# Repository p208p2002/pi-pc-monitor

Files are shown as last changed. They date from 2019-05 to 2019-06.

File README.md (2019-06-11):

# LED電腦資源監控燈 / Pi PC monitor
A Pi PC state monitor design for NUTC final project.

Monitor with CPU and RAM usage state.

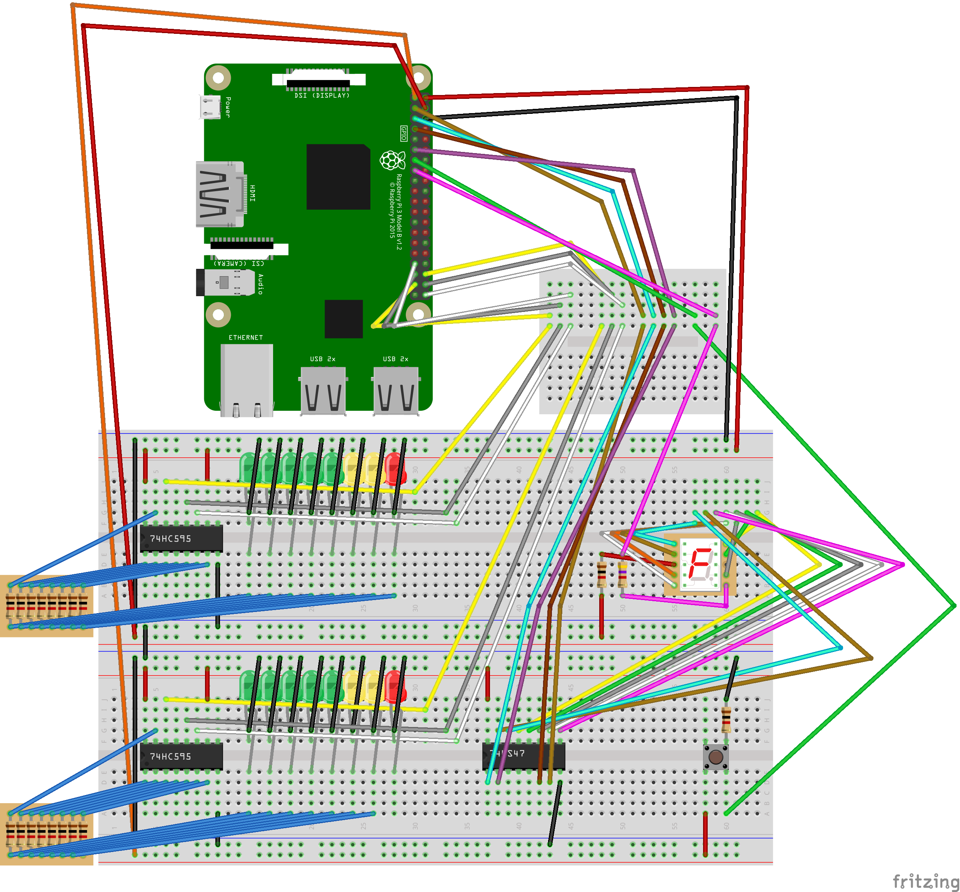
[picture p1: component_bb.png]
component


[Video 1](https://www.youtube.com/watch?v=h-WTSqjy7dE)

[Video 2](https://www.youtube.com/watch?v=xZc-PM7hHug)

# Usage
- put `server_pi.py` on Rasbperry Pi and run with Python 3
- put `client_pc.py` on your PC and run with `python3 --host=YOUR_PI_SERVER_IP`

# File description
file name     | description
--------------|------------
client_pc.py  | client code
core.py       | get PC state info (for client)
server_pi.py  | server code
ic.py         | ic driver class (for server)
component.fzz | Fritzing file
document.docx | design document

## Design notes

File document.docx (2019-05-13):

## Pi期末專題

Physical PC state monitor with Pi

黃柏鈞

黃耕易

吳靚玹

鄭安志

侯宇濤

1. 專題大綱

使用Raspberry Pi搭建一組PC資源狀態監控器，可實時反映被監控端CPU與RAM使用率，監控主機與被控端將以socket進行通訊並搭配Pi的GPIO將狀態以實體元件顯示。

2. 系統目的

有時候我們常常使用電腦進行大量資源的運算，但是卻常常不知道電腦目前的負載狀態，到底是處於高負載還是有閒置效能。

相比直接將資源狀態顯是於螢幕上的軟體，本專題使用的實體燈號具有以下優勢:

1. 在電腦全螢幕模式下無須切換視窗(相較非懸浮監控軟體)

2. 不會因佔用畫面而導致遮蓋掉畫面資訊(相較懸浮監控軟體)

3. 獨立顯示設備可作為桌面裝飾品

4. 更容易了解電腦負載狀態

3. 系統架構

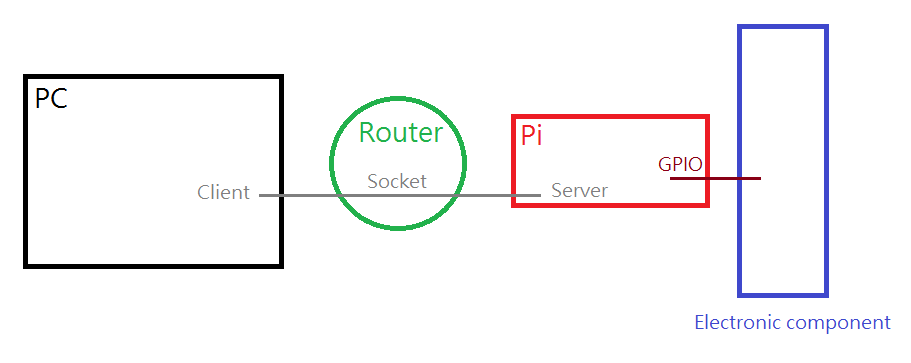
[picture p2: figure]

- PC與Pi會在同一個區域網路
- 在Pi上建立socket server負責接收資料
- PC上則有socket client負責丟資料
- Pi接受到資料後進行解析並且將結果透過GPIO輸出至電子元件

4. 系統流程圖

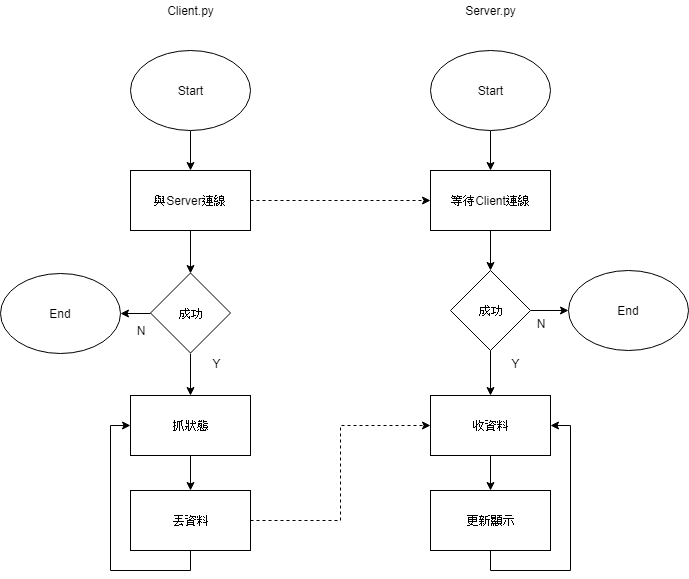
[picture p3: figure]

5. 使用技術與設備

名稱 | 說明
Raspberry Pi 3 Model B+ | 監控主機與電子元件控制
Python 3 | 主要開發語言
Git | 版本控制

6. 使用元件

名稱 | 數量 | 用途
LED(綠) | 10 | 狀態陣列
LED(黃) | 4 | 狀態陣列
LED(紅) | 2 | 狀態陣列
74595 | 2 | LED控制
7447 | 1 | 七段顯示器控制
七段顯示器 | 1 | 顯示Server IP資訊
按鈕 | 1 | 功能觸發
1k 電阻 | 18 | 七段顯示器與LED電阻
4.7k 電阻 | 1 | 七段顯示器電阻

7. 電路佈局

7.1 總覽

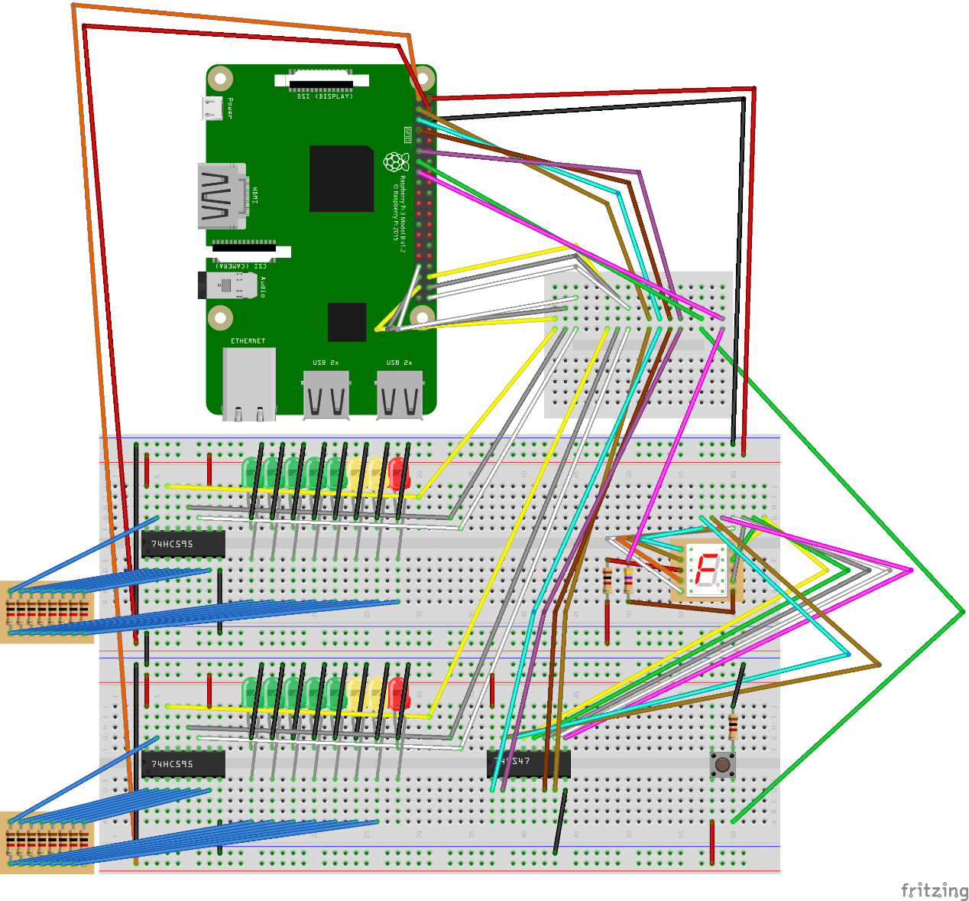
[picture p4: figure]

7.2 局部特寫與功能說明

7.2.1 Part A

gpio | 功能
2 | 7447 PIN A
3 | 7447 PIN B
4 | 7447 PIN C
17 | 7447 PIN D
22 | 小數點
27 | 按鈕

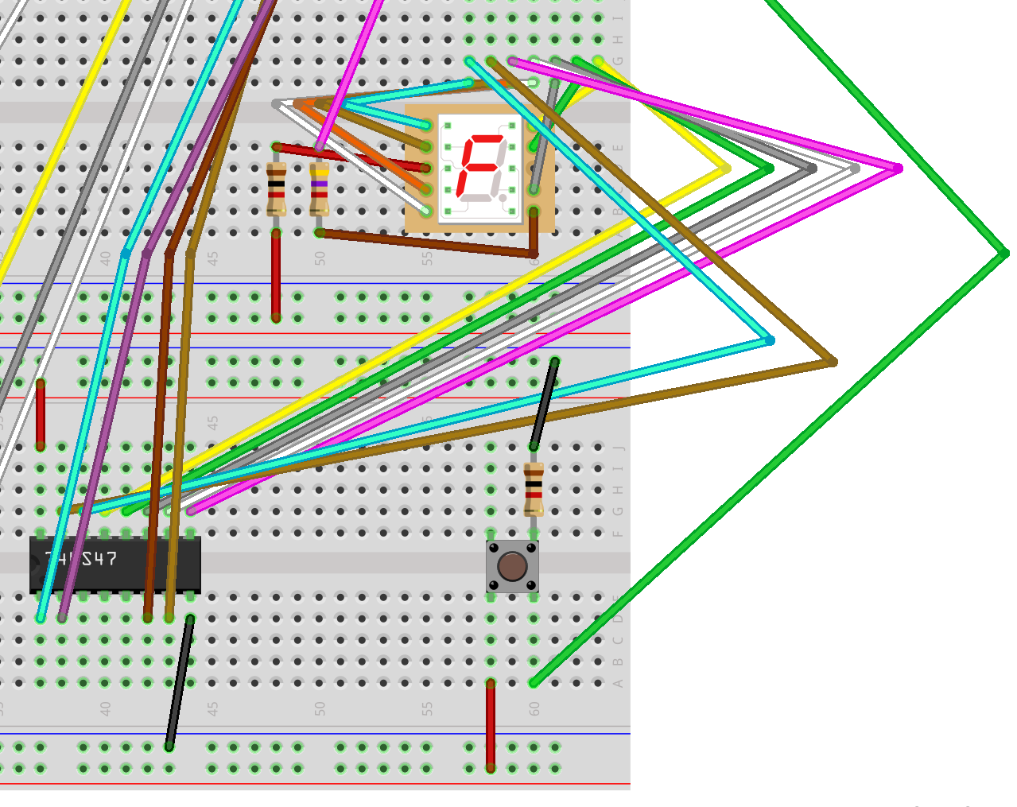
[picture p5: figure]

gpio 22

gpio 27

gpio 17

gpio 4

gpio 3

gpio 2

7.2.2 Part B

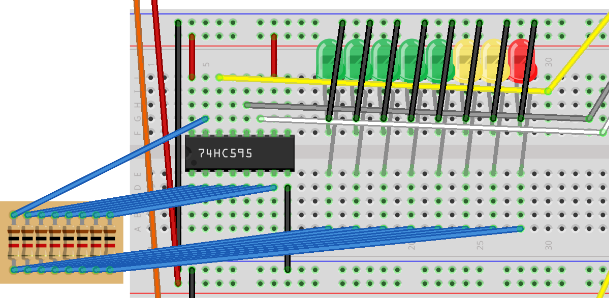
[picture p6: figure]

gpio 21/13

gpio 20/19

gpio 16/26

gpio | 功能
16/26 | 74595 DS
20/19 | 74595 STCP
21/13 | 74595 SHCP

8. 通訊格式定義

資料格式:Json

格式結構:

{

"Type":EVENT_TYPE

"Data":DATA,

}

8.1 EVENT TYPE

8.1.1 BASIC_MSG

包含被監控端基本資訊

{

"Type": "BASIC_MSG",

"Data": {

"CPU_Model": String,

"CPU_Count": Int,

"CPU_Count_Logical": Int,

"RAM_Total_Size": Float

}

}

8.1.2. USAGE_MSG

包含被監控端資源使用量資訊

{

"Type": "USAGE_MSG",

"Data": {

"CPU_PERCENT":String,

"MEM_USED": Int

}

}

9. 系統部屬與操作

1. 參照5、6章節先將硬體準備完畢

2. 至Project Repo(參閱第9章節)將檔案下載

3. 將client_pc.py與core.py放置在欲監控之電腦

4. 將server_pi.py與ic.py放置在Raspberry Pi

5. 確保Raspberry Pi與欲監控之電腦在同一區域網路

5. 在Raspberry Pi輸入指令python3 server_pi.py運行Server端

6. 按下Raspberry Pi之”按鈕”，七段顯示器將顯示Server IP

7. 在欲監控之電腦輸入指令python3 client_py –port=YOUR_SERVER_IP

YOUR_SERVER_IP為七段顯示器所顯示IP

10. 附件

1. Project Repo : https://github.com/p208p2002/pi-pc-monitor

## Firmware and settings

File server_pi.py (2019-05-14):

import socket
import sys
import argparse
import json
import time
import RPi.GPIO as gpio
import signal
import sys
from ic import IC74595,IC7447

host = ''
data_payload = 4096
backlog = 1

#
gpio.setmode(gpio.BCM)

#
DS = 16     # Serial Data
STCP = 20  # Latch
SHCP = 21  # Clock

DS2 = 26
STCP2 = 19
SHCP2 = 13

IC_7447_A = 2
IC_7447_B = 3
IC_7447_C = 4
IC_7447_D = 17

#
MachineInfo={}
LED_STATE = [0,128,192,224,240,248,252,254,255] #0 1 2 3 4 5 6 7 8

#
BTN_PIN = 27
DOT_PIN = 22
SERVER_IP = 0

#parts
digNumDisplay = IC7447(IC_7447_A,IC_7447_B,IC_7447_C,IC_7447_D,DOT_PIN)
cpuLED = IC74595(DS,STCP,SHCP)
ramLED = IC74595(DS2,STCP2,SHCP2)

def signal_handler(sig, frame):
    gpio.cleanup()
    sys.exit(0)

def showIP(channel):
    if (SERVER_IP == 0):
        digNumDisplay.off()
    else:
        for i in range(len(SERVER_IP)):
            if(SERVER_IP[i] != '.'):
                digNumDisplay.show(int(SERVER_IP[i]))
                digNumDisplay.dot(False)
            else:
                digNumDisplay.off()
                digNumDisplay.dot(True)
            time.sleep(0.5)
        digNumDisplay.off()
        digNumDisplay.dot(False)

def showServerIP():
    return [(s.connect(('8.8.8.8', 53)), s.getsockname()[0], s.close()) for s in [socket.socket(socket.AF_INET, socket.SOCK_DGRAM)]][0][1]

def showMonitorState():
    cpuModel = MachineInfo.get('CPU_Model','unkonw')
    cpuCount = MachineInfo.get('CPU_Count','unkonw')
    cpuCountLogical = MachineInfo.get('CPU_Count_Logical','unkonw')
    ramTotalSize = MachineInfo.get('RAM_Total_Size','unkonw')
    print("Machine Info:",cpuModel,str(cpuCount)+'C'+str(cpuCountLogical)+'T',str(ramTotalSize)+'MB')

def mapStateToLed(usedPrecent,pipNumber):
        led = 0
        if pipNumber == 1:
            led = cpuLED
        elif pipNumber == 2:
            led = ramLED

        if(usedPrecent==0):
            led.shiftout(LED_STATE[0])
        elif(usedPrecent<=12.5):
            led.shiftout(LED_STATE[1])
        elif(usedPrecent<=25.0):
            led.shiftout(LED_STATE[2])
        elif(usedPrecent<=37.5):
            led.shiftout(LED_STATE[3])
        elif(usedPrecent<=50.0):
            led.shiftout(LED_STATE[4])
        elif(usedPrecent<=62.5):
            led.shiftout(LED_STATE[5])
        elif(usedPrecent<=75.0):
            led.shiftout(LED_STATE[6])
        elif(usedPrecent<=87.5):
            led.shiftout(LED_STATE[7])
        elif(usedPrecent<=100):
            led.shiftout(LED_STATE[8])
        else:
            led.shiftout(0)


def updateMonitorState(jsonStr):
    global MachineInfo
    jsonData={}
    try:
        jsonData = json.loads(jsonStr)
    except:
        print("Parse json data fail")

    eventType = jsonData.get("Type")
    print("Event Type:",eventType)

    #case event type
    if(eventType == 'BASIC_MSG'):
        data = jsonData.get('Data',{})
        MachineInfo = data
    elif(eventType == 'USAGE_MSG'):
        data = jsonData.get('Data',{})
        cpuUsed = float(data.get('CPU_PERCENT',0.0))
        memUsed = float(data.get('MEM_USED',0.0))
        mapStateToLed(cpuUsed,1)
        mapStateToLed(memUsed,2)
        print(cpuUsed,memUsed)
    else:
        print('unknow event type')

    # final
    showMonitorState()


def runSocketServer(port):
    sock = socket.socket(socket.AF_INET, socket.SOCK_STREAM)
    sock.setsockopt(socket.SOL_SOCKET, socket.SO_REUSEADDR, 1)
    server_address = (host, port)
    print ("Starting up server  on %s port %s" % server_address)
    sock.bind(server_address)
    sock.listen(backlog)

    #
    print ("Waiting new client")
    client, address = sock.accept()
    print("Address:",address)

    #time out count
    timeOut = 10.0
    lastRecvTime = time.time()
    nowtime = time.time()
    while True:
        #over 10s no recv new data
        if(nowtime - lastRecvTime >= timeOut):
            print("client lost connect")
            client.close()
            print ("Waiting new client")
            client, address = sock.accept()
            lastRecvTime = time.time()
            nowtime = time.time()

        nowtime = time.time()#refresh time out count
        data = client.recv(data_payload)#recv data
        if data:
            digNumDisplay.dot(True)
            lastRecvTime = time.time()
            updateMonitorState(data.decode())
        digNumDisplay.dot(False)

if __name__ == '__main__':
    #init
    gpio.setup(DOT_PIN, gpio.OUT)
    gpio.setup(BTN_PIN, gpio.IN, pull_up_down=gpio.PUD_DOWN) # Set pin 10 to be an input pin and set initial value to be pulled low (off)
    gpio.add_event_detect(BTN_PIN,gpio.RISING,callback=showIP,bouncetime=1000) # Setup event on pin 10 rising edge
    signal.signal(signal.SIGINT, signal_handler)

    #self test
    for x in range(9):
        cpuLED.shiftout(LED_STATE[x])
        ramLED.shiftout(LED_STATE[x])
        digNumDisplay.show(x+1)
        time.sleep(0.05)

    for x in range(9):
        cpuLED.shiftout(LED_STATE[8-x])
        ramLED.shiftout(LED_STATE[8-x])
        digNumDisplay.show(9-x)
        time.sleep(0.05)

    digNumDisplay.off()

    #
    parser = argparse.ArgumentParser(description='Socket Server Example')
    parser.add_argument('--port', action="store", dest="port", type=int, default=8080)
    given_args = parser.parse_args()
    port = given_args.port
    SERVER_IP=showServerIP()
    print(SERVER_IP)
    runSocketServer(port)

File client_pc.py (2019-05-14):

import socket
import sys
import argparse
import time
from core import getBasicMsg,getUsageMsg


defaulthost = '192.168.43.50'
defaultPort = 8080

def pc_client(host,port):
    sock = socket.socket(socket.AF_INET, socket.SOCK_STREAM)
    server_address = (host, port)
    sock.connect(server_address)
    sock.send(getBasicMsg().encode('utf-8'))
    while True:
        sock.send(getUsageMsg().encode('utf-8'))
        time.sleep(0.25)
    sock.close()



if __name__ == '__main__':
    parser = argparse.ArgumentParser(description='Socket Server Example')
    parser.add_argument('--port', action="store", dest="port", type=int, default=defaultPort)
    parser.add_argument('--host', action="store", dest="host", type=str, default=defaulthost)
    given_args = parser.parse_args()
    port = given_args.port
    host = given_args.host
    pc_client(host,port)
